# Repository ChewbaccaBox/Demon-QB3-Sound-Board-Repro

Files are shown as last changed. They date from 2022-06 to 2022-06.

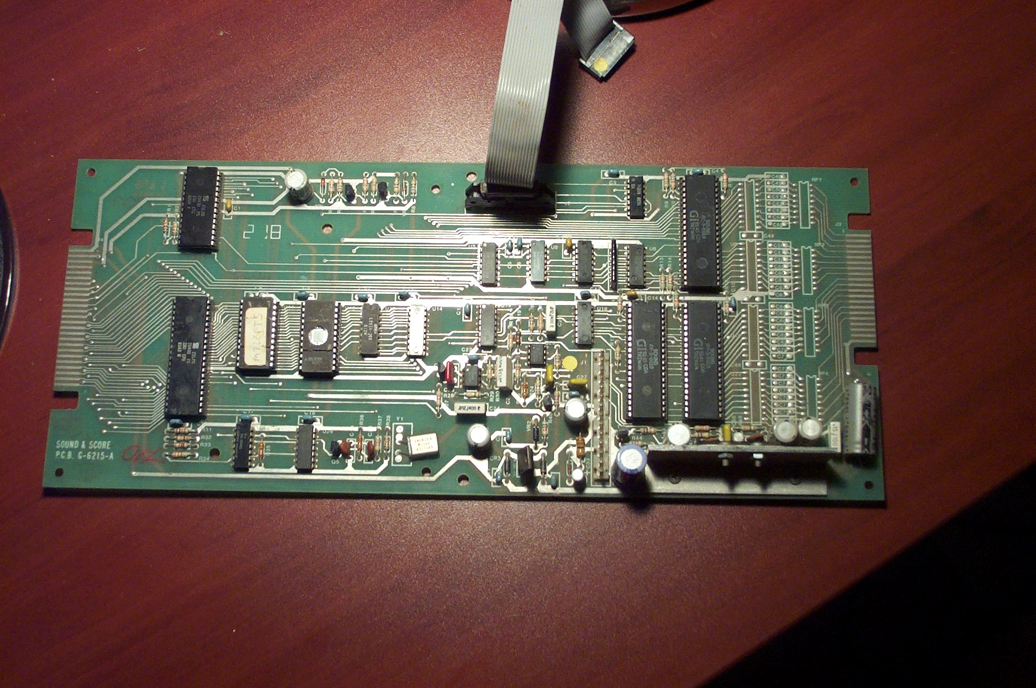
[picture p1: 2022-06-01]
Images/other.png

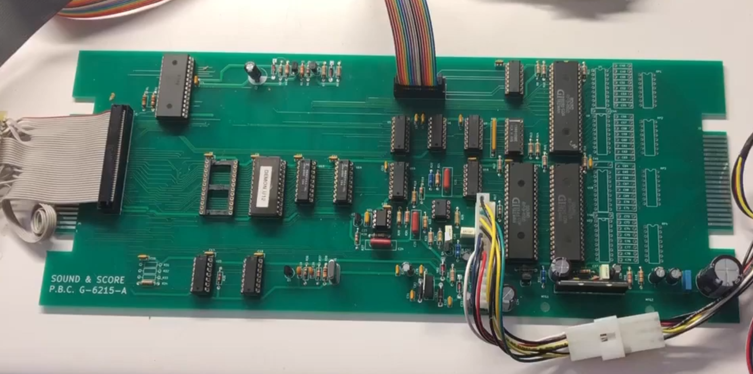
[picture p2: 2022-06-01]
Images/toledoflyerRepro.png

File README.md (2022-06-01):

# Demon-QB3-Sound-Board

***UNTESTED AND POSSIBLY INCOMPLETE***\
Gerbers not included because of this.

Here is my reproduction sound board of those
used in Rockola's Demon and QB3, both based
on Cinematronics hardware. 
So, these games are both impossible to find,
and therefore the sound boards are too.
Demon uses practically a standard Cinematronics
CPU board, and QB3 is a bit more complicated
to make hardware for, but this sound board
should work for the two games.
(QB3 has more ram, a color converter PCB, the sound roms
 dumped are broken. But Demon should work with less trouble!)

**TESTING STATUS:**

no clue! gotta double check the schematic based on the original.
This is being built on solely the two schematics (the QB3 one 
looks more accurate/complete, so leaning towards that one)

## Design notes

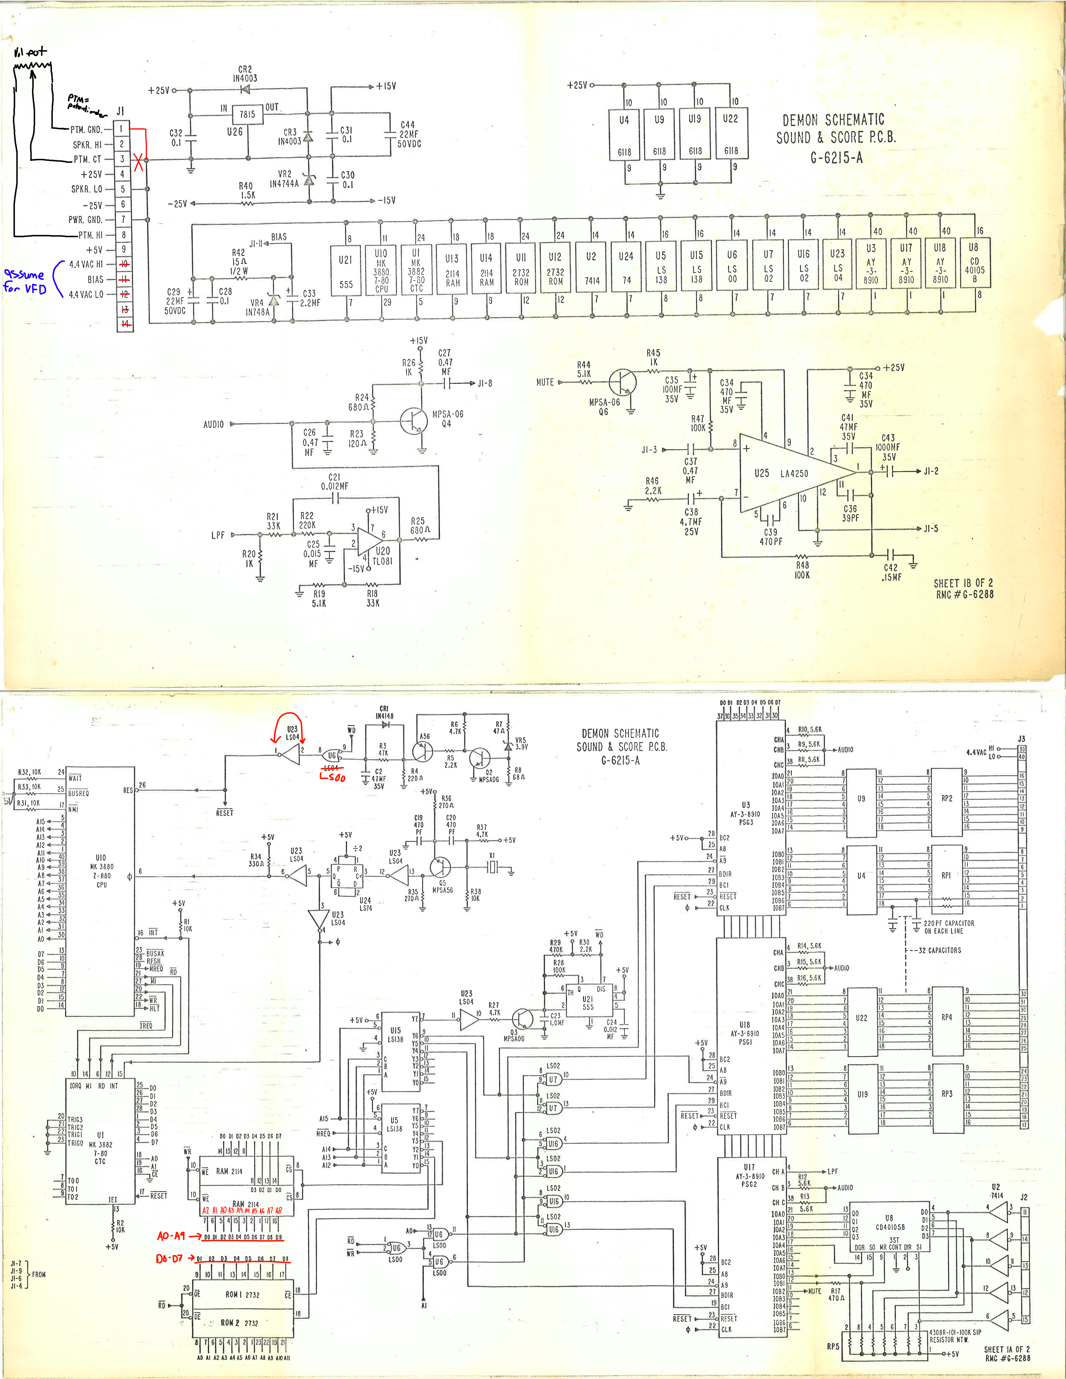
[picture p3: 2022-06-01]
Images/DemonSchematic.png

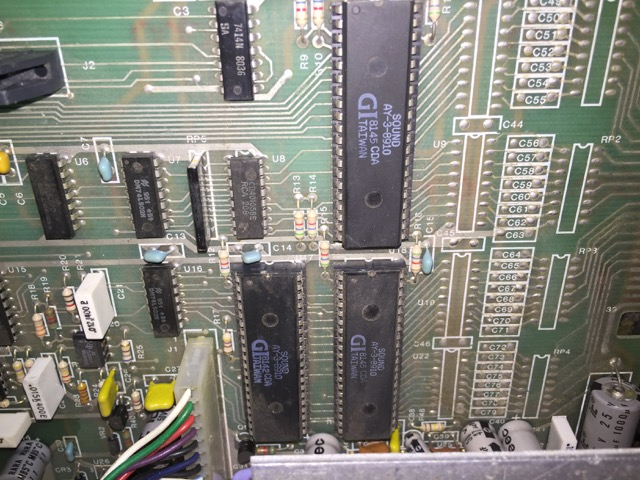
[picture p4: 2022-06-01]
Images/OGpic3.png

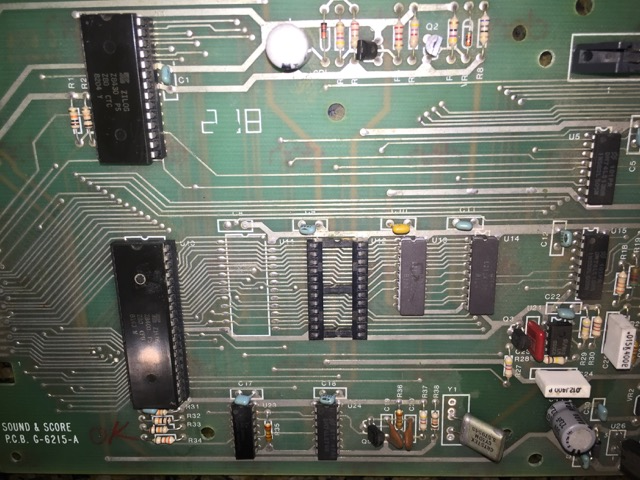
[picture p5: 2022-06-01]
Images/OGpic2.png

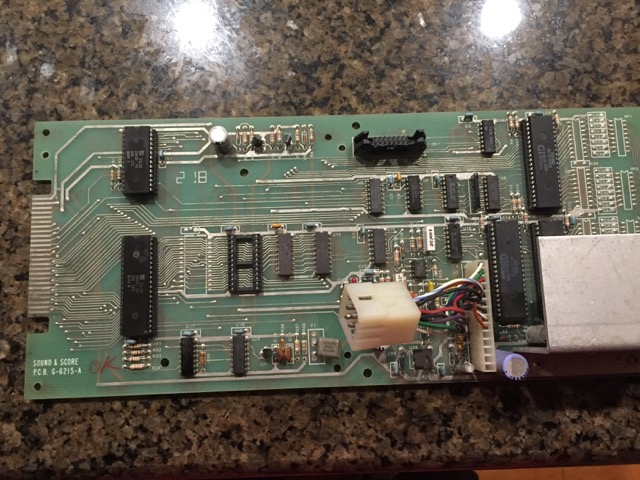
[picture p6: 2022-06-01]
Images/OGpic1.png

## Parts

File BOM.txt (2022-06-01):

    C1 		Right of MK3880			Orange
    C2		47uF				Electrolytic
    C3		Top Left of U2			Blue
    C4		Above U3			
    C5		Left of u6			
    C6		Left of u6			
    C7 		beside u7			
    C8		above u11 (if installed)	
    C9 		above u12			
    C10 	above u13			
    C11 	above u14			
    C12		beside U15			
    C13		above u16			
    C14		above u17			
    C15		Right of R10			
    C16		Below z80			Blue
    C17		above u23			Blue
    C18		above u24			
    C22		above 555

    C19		470pF
    C20		470pF
    C21		0.012uF
    C23		1uF
    C24		0.012uF
    C25		0.015uF
    C26		0.47uF
    C27		0.47uF
    C28		0.1uF
    C29		22uF
    C30		0.1uF
    C31		0.1uF
    C32		0.1uF
    C33		2.2uF
    C34		470uF
    C35		100uF
    C36		39pF
    C37		0.47uF
    C38		4.7uF
    C39		470pF
    C40		470uF
    C41		47uF
    C42		.15uF
    C43		1000uF
    C44		22nF
    C45		above u19
    C46		above u22

    C47		?

    C48 - C79   =   CA1 - CA32

    CA1		220pF
    CA2		220pF
    CA3		220pF
    CA4		220pF
    CA5		220pF
    CA6		220pF
    CA7		220pF
    CA8		220pF
    CA9		220pF
    CA10	220pF
    CA11	220pF
    CA12	220pF
    CA13	220pF
    CA14	220pF
    CA15	220pF
    CA16	220pF
    CA17	220pF
    CA18	220pF
    CA19	220pF
    CA20	220pF
    CA21	220pF
    CA22	220pF
    CA23	220pF
    CA24	220pF
    CA25	220pF
    CA26	220pF
    CA27	220pF
    CA28	220pF
    CA29	220pF
    CA30	220pF
    CA31	220pF
    CA32	220pF

    CR1		1N4148
    CR2		1N4003
    CR3		1N4003

    J1		14 pin .156 header, 1 x 14
    J2		16 pin .1 header, 2 x 8
    J3		(Edge connector, part of PCB already)
    J4		(Edge connector, part of PCB already)

Transistors
	5 * MPSA06, 1 * MPSA92

    Q1		MPSA06
    Q2		MPSA06
    Q3		MPSA06
    Q4		MPSA06
    Q5		MPSA92
    Q6		MPSA06

Resistors

    R1		10K
    R2		10K
    R3		47K
    R4		220
    R5		47K
    R6		4.7K
    R7		47K
    R8		68
    R9		5.6K
    R10		5.6K
    R11		5.6K
    R12		5.6K
    R13		5.6K
    R14		5.6K
    R15		5.6K
    R16		5.6K
    R17		470
    R18		33K
    R19		5.1K
    R20		1K
    R21		33K
    R22		220K
    R23		120
    R24		680
    R25		680
    R26		1K
    R27		4.7K
    R28		100K
    R29		470K
    R30		2.2K
    R31		10K
    R32		10K
    R33		10K
    R34		330
    R35		270
    R36		270
    R37		4.7k
    R38		10K
    R40		1.5K
    R42		15
    R44		5.1K
    R45		1K
    R46		2.2k
    R47		100K
    R48		100K
    RP1		R_Pack08
    RP2		R_Pack08
    RP3		R_Pack08
    RP4		R_Pack08
    RP5		100K

Chips / Packages
	3 * AY-3-8910, 2 * 2114, 2 * 2732, 1 * Z80, 1 * Z

    U1		MK3882
    U2		74LS14
    U3		AY-3-8910
    U4		6118
    U5		74LS138
    U6		74LS00
    U7		74LS02
    U8		CD40105B
    U9		6118
    U10		Z80CPU
    U11		2732
    U12		2732
    U13		2114
    U14		2114
    U15		74LS138
    U16		74LS02
    U17		AY-3-8910
    U18		AY-3-8910
    U19		6118
    U20		TL081
    U21		555
    U22		6118
    U23		74LS04
    U24		74LS74
    U25		LA4250
    U26		7815
    VR2		1N4744A
    VR4		1N748A
    VR5		?

Crystals
	1 * 3.579 MHz

    X1		3.579 MHz

chips

3 x AY-3-8910
1 x LA4250
1 x TL081
2 x 2114
1 x 2732	
1 x CD40105B
1 x Z80
1 x Z80-CTC

1 x 74LS00
2 x 74LS02
1 x 74LS04
1 x 74LS14
1 x 74LS74
2 x 74LS138

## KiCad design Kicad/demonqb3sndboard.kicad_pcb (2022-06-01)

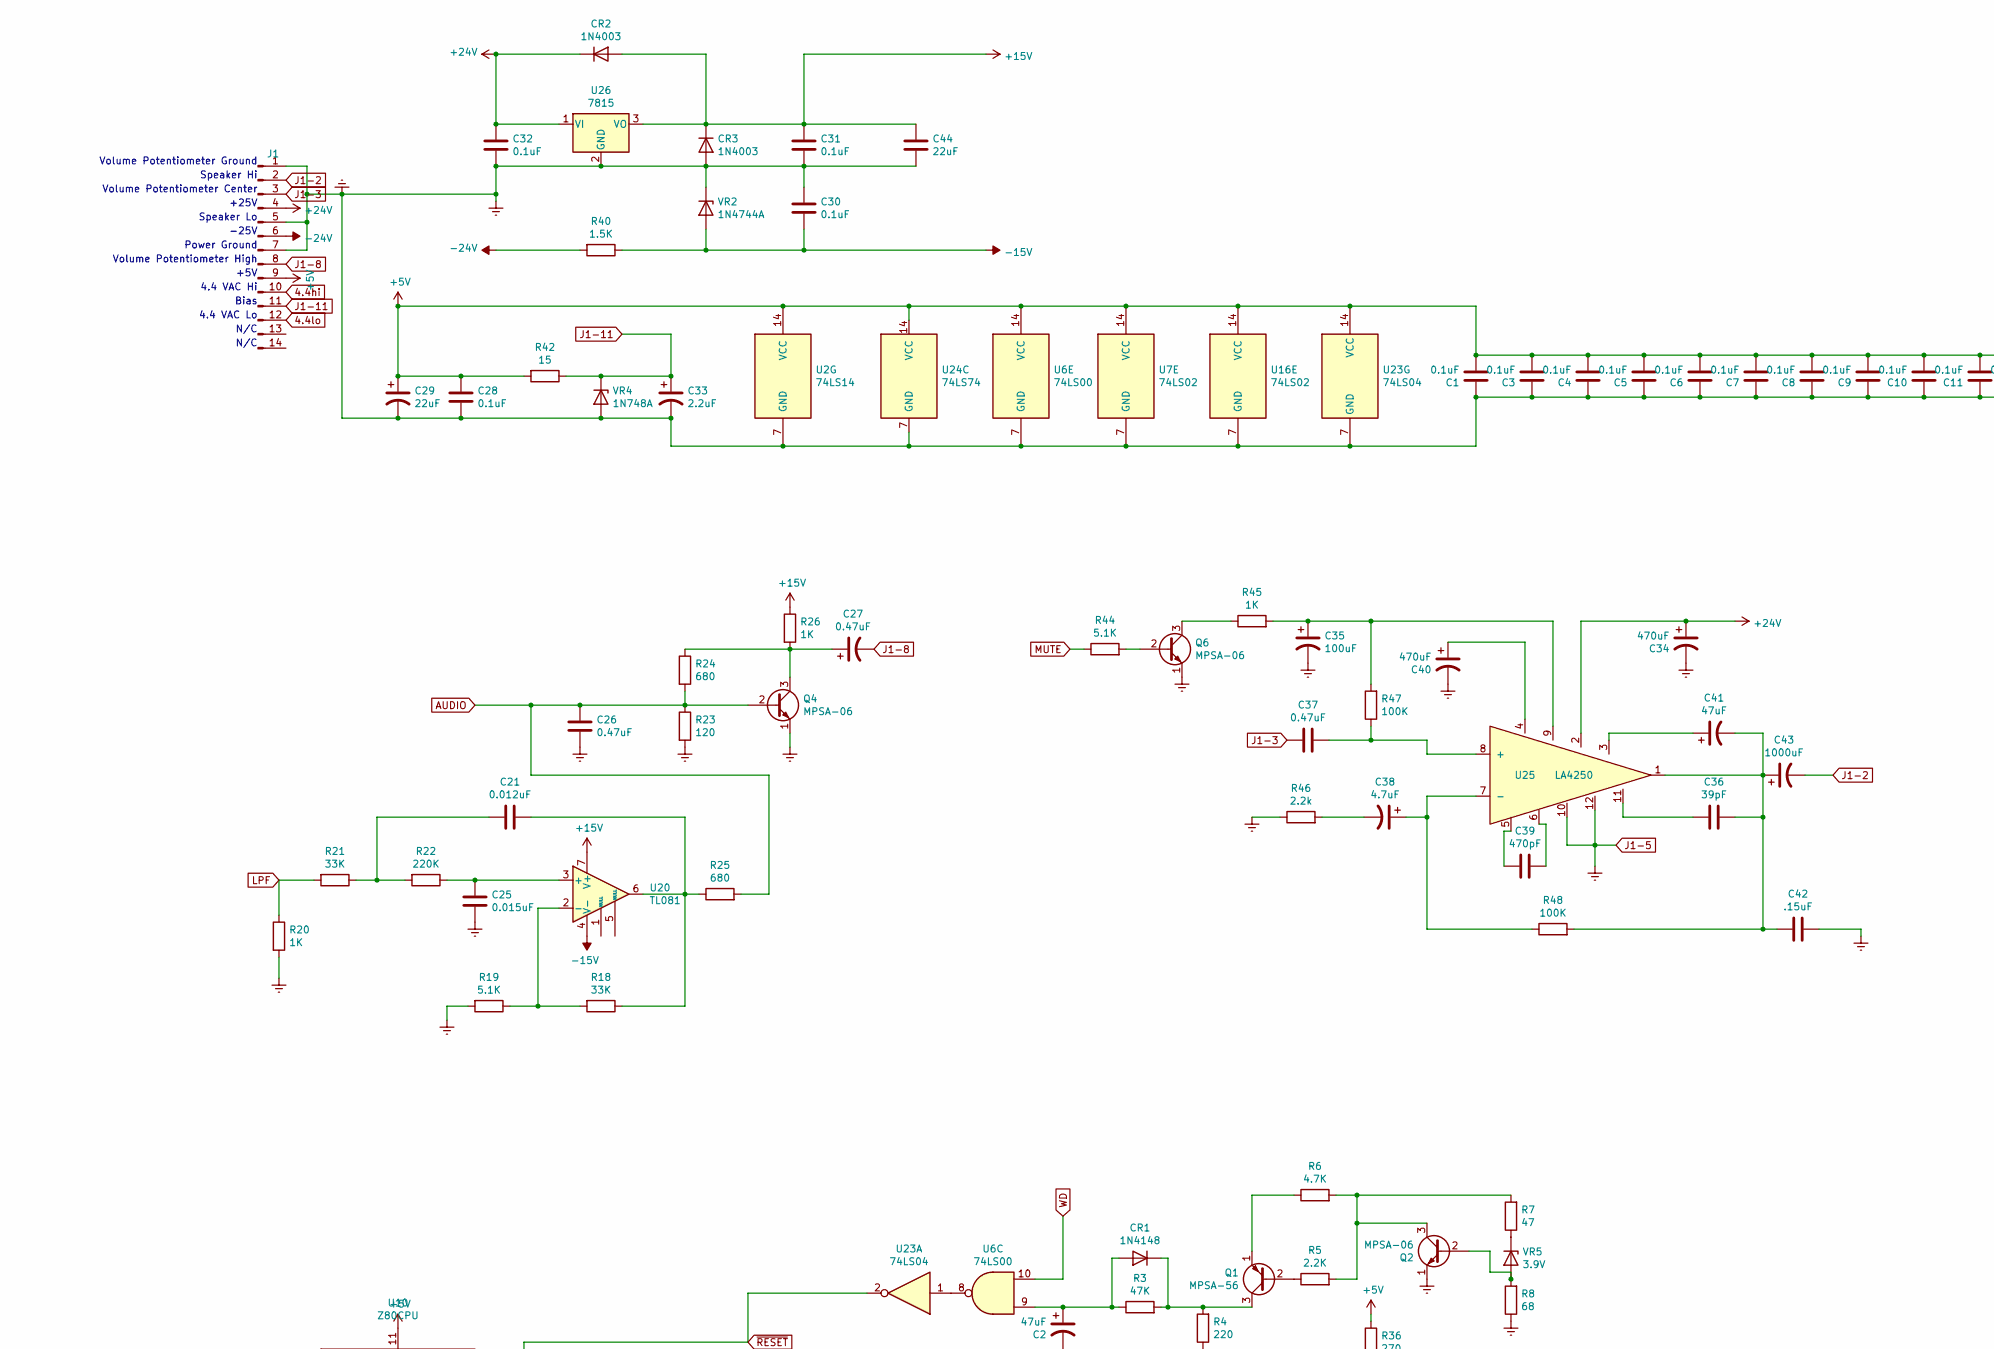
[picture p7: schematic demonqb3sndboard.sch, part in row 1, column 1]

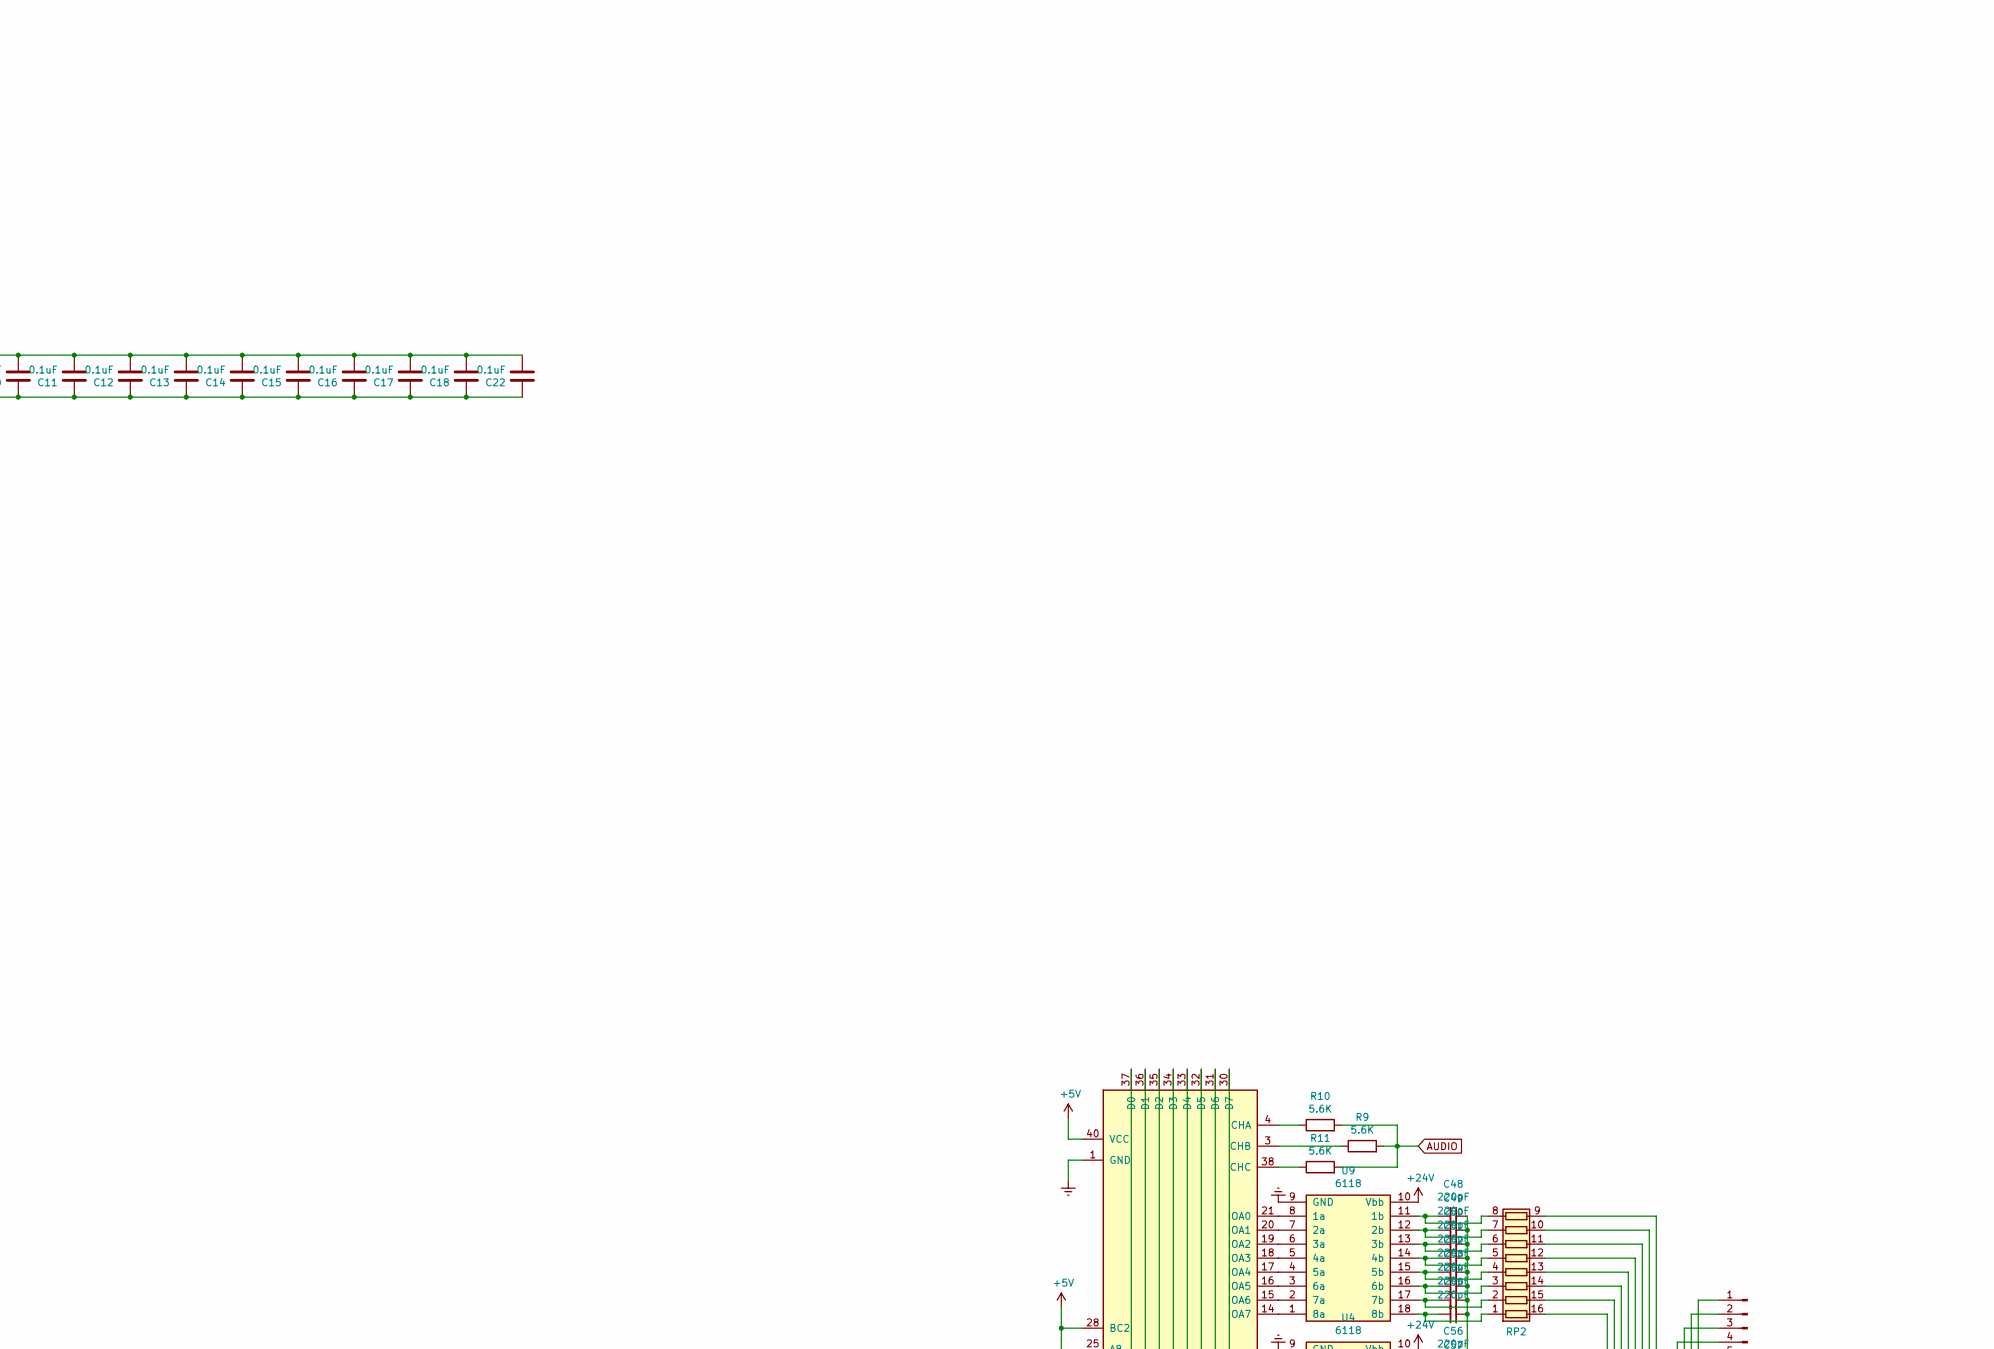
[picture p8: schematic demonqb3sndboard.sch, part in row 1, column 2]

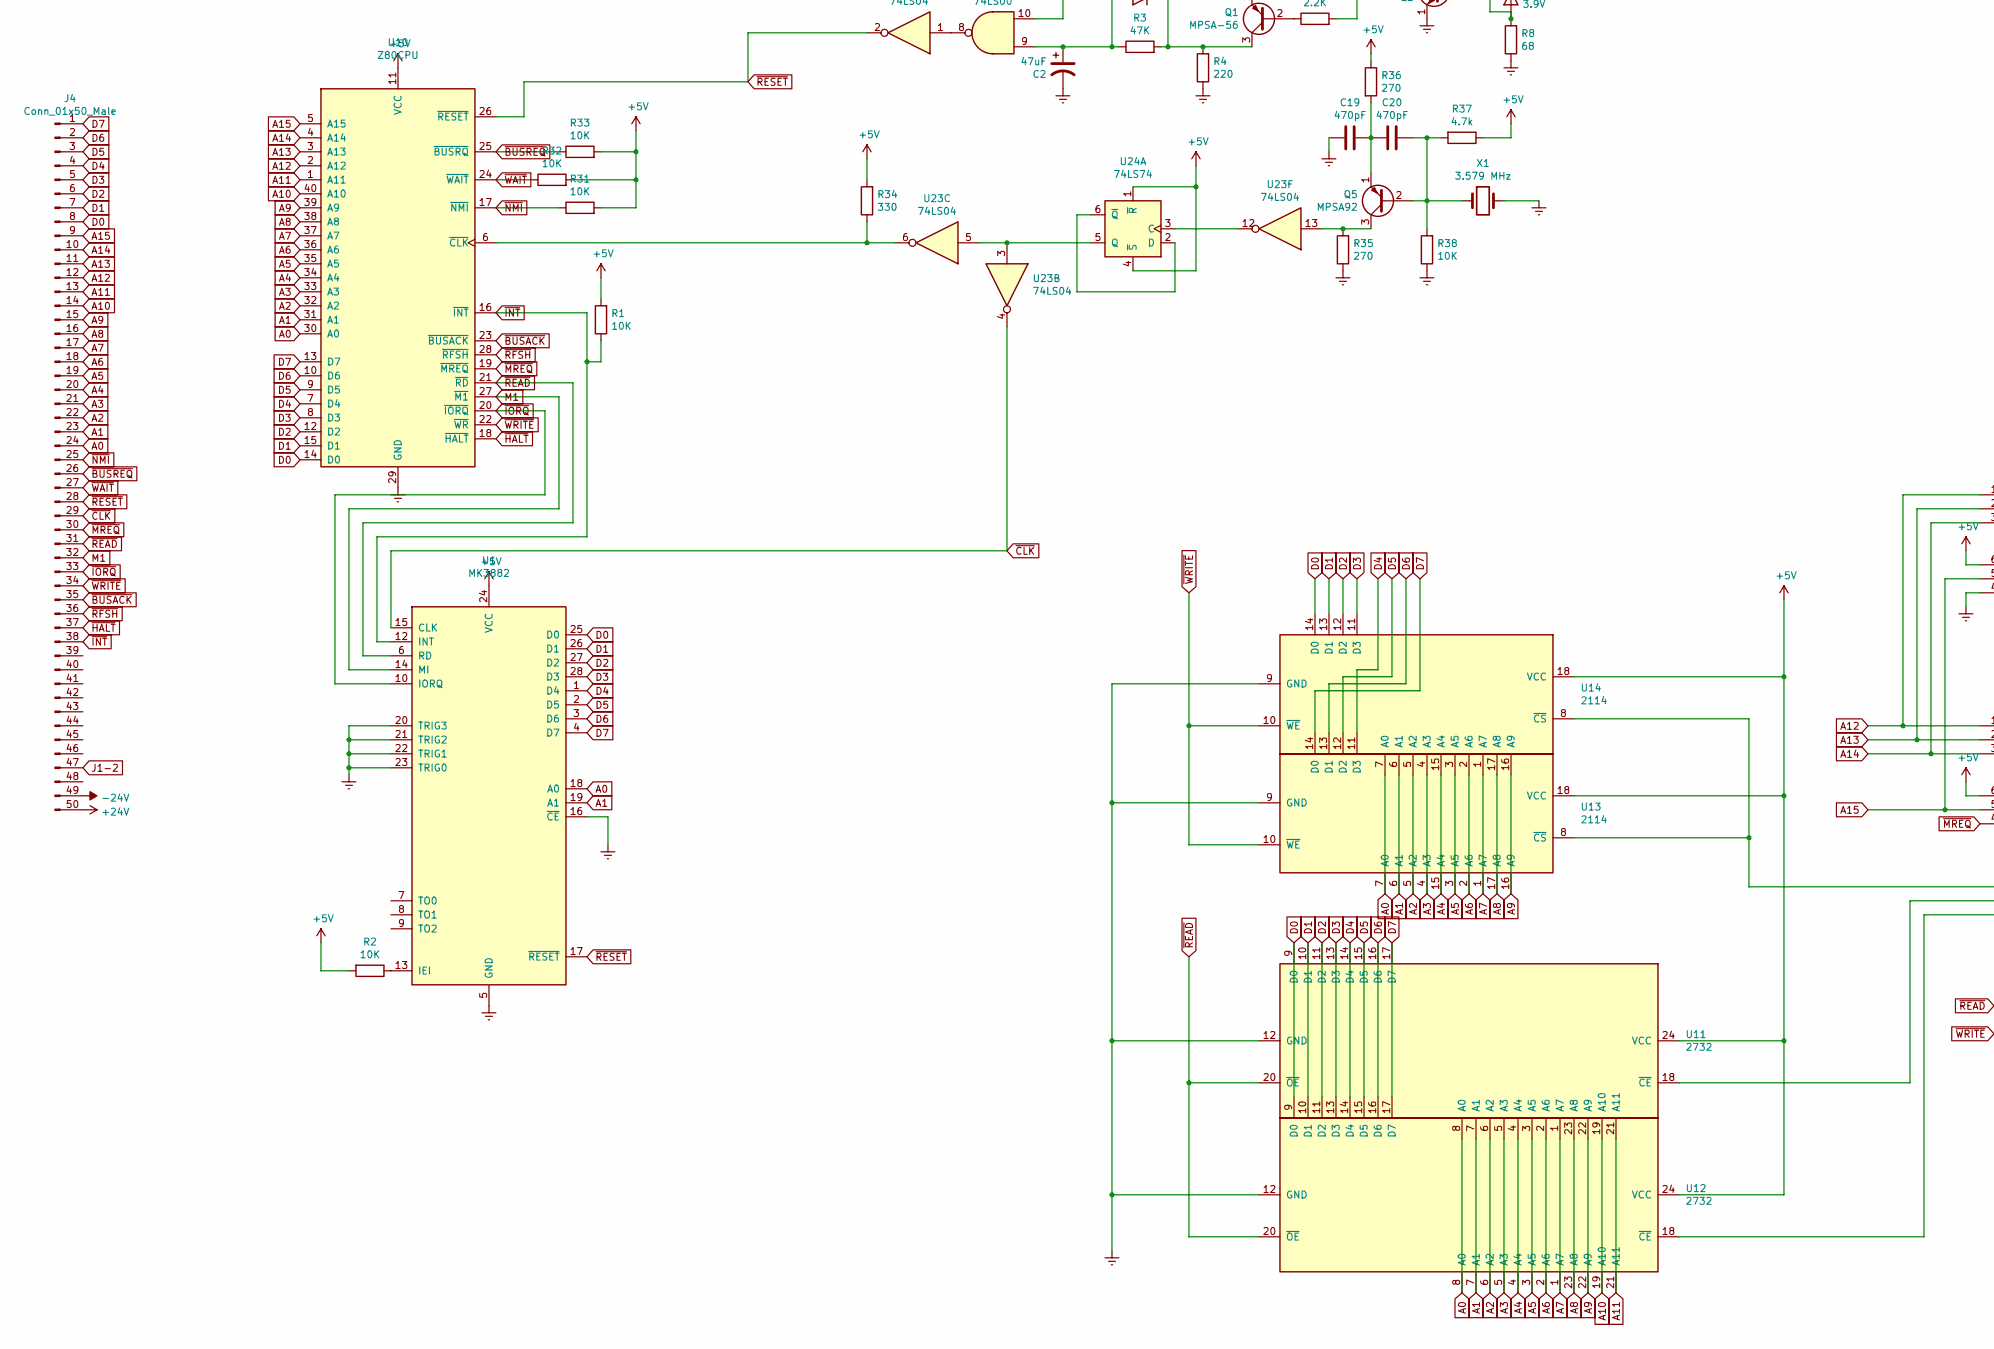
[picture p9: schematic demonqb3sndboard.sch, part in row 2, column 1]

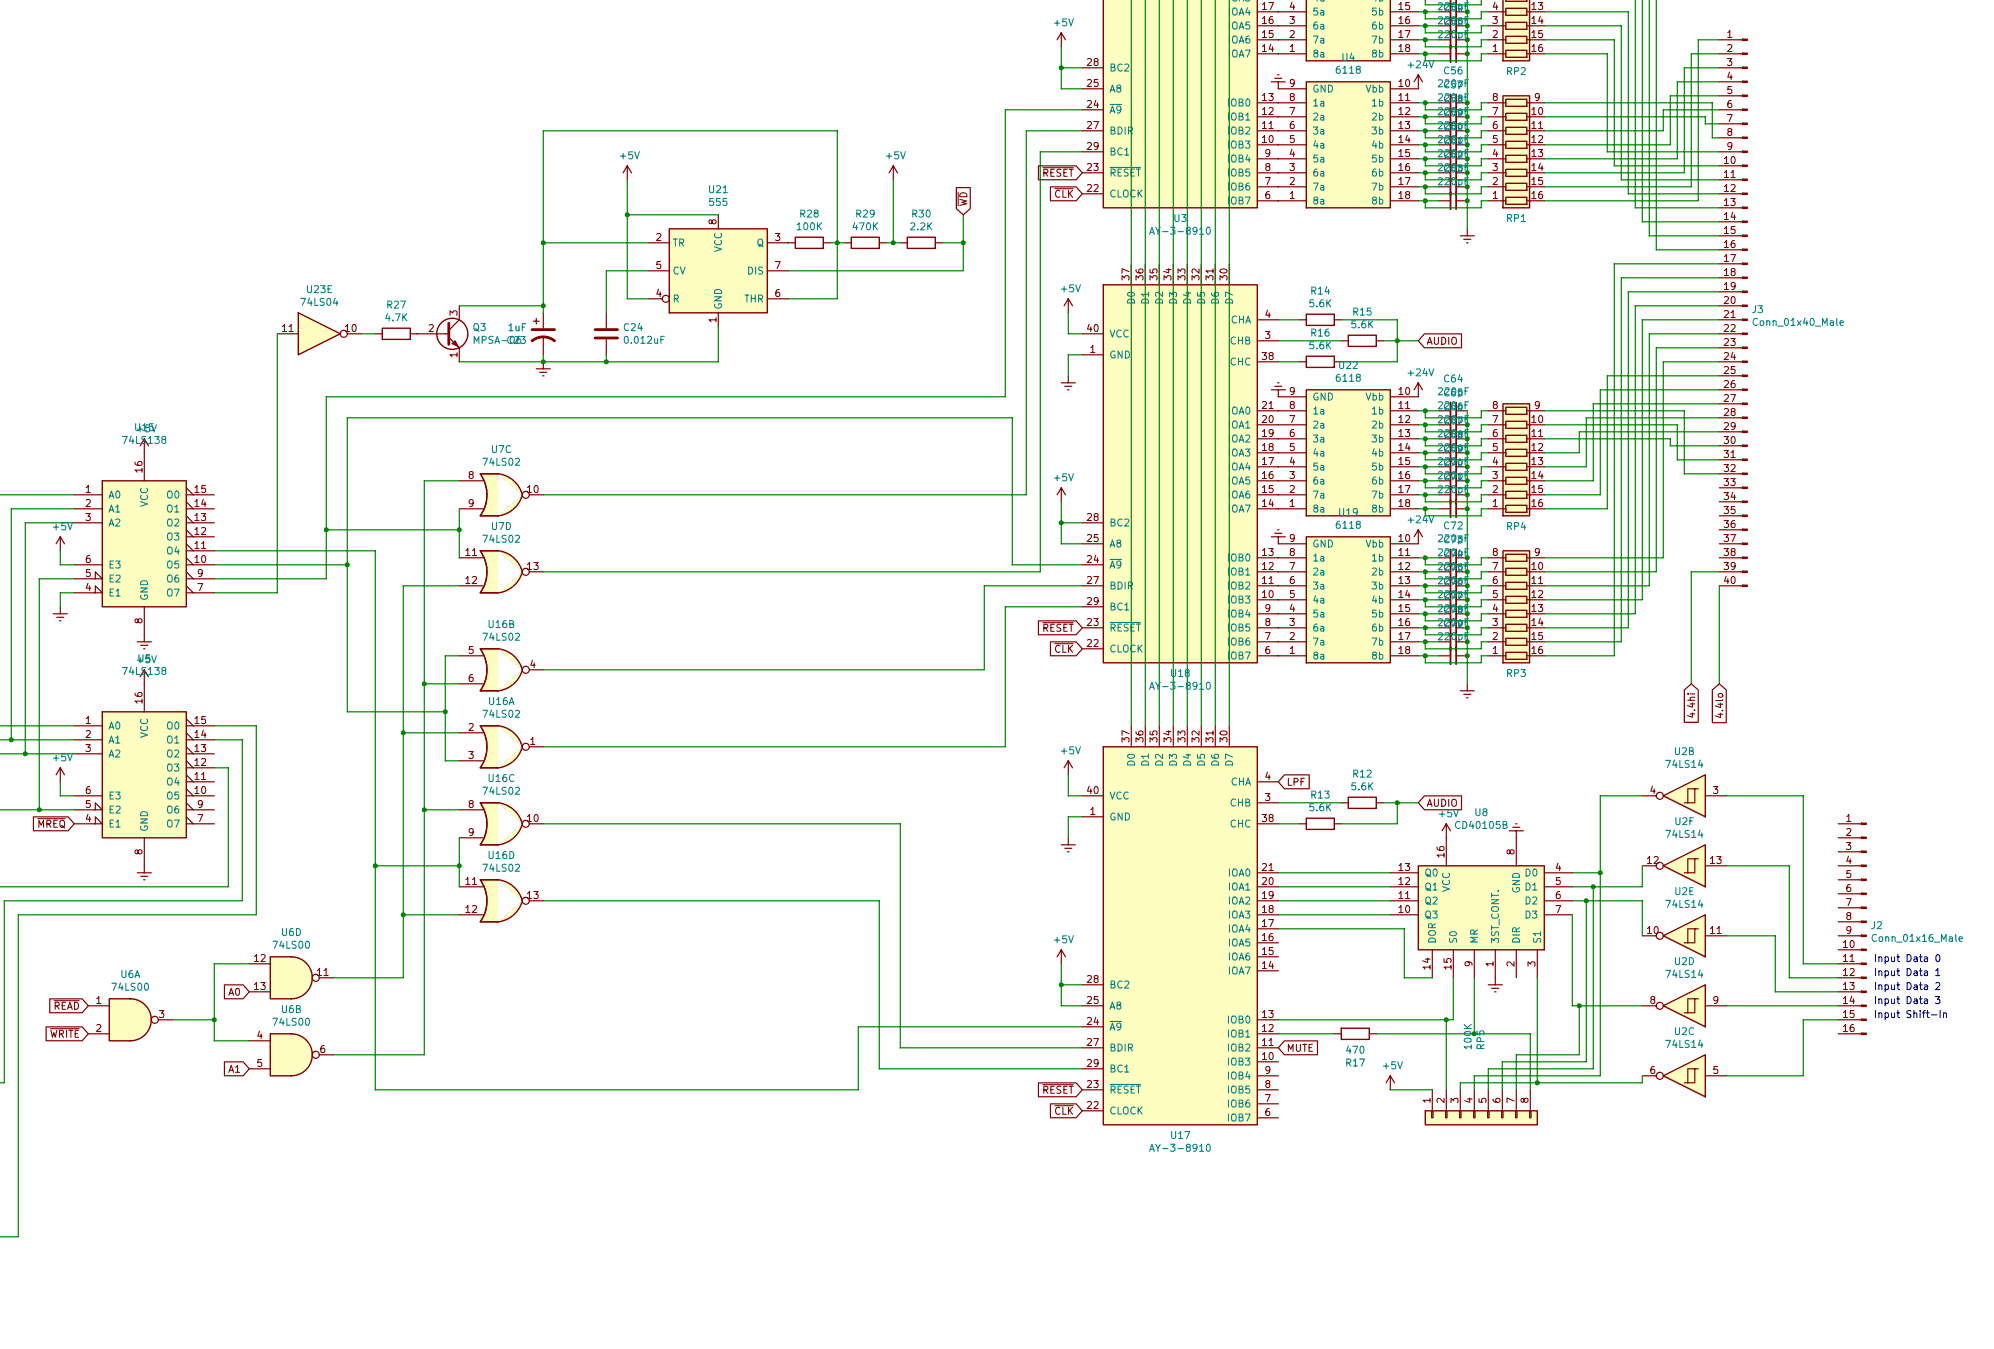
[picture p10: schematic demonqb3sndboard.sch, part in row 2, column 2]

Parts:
C1, C3, C4, C5, C6, C7, C8, C9, C10, C11, C12, C13, C14, C15, C16, C17, C18, C22, C28, C30, C31, C32: 0.1uF; C_Disc_D7.0mm_W2.5mm_P5.00mm
C2: 47uF; CP_Radial_D10.0mm_P5.00mm
C19, C20, C39: 470pF; C_Disc_D7.0mm_W2.5mm_P5.00mm
C21, C24: 0.012uF; C_Disc_D12.5mm_W5.0mm_P10.00mm
C23: 1uF; C_Disc_D10.0mm_W2.5mm_P5.00mm
C25: 0.015uF; C_Disc_D12.5mm_W5.0mm_P10.00mm
C26, C27: 0.47uF; C_Disc_D7.0mm_W2.5mm_P5.00mm
C29, C44: 22uF; C_Disc_D7.0mm_W2.5mm_P5.00mm
C33: 2.2uF; C_Disc_D7.0mm_W2.5mm_P5.00mm
C34, C40: 470uF; CP_Radial_D10.0mm_P5.00mm
C35: 100uF; CP_Radial_D5.0mm_P2.50mm
C36: 39pF; C_Disc_D7.0mm_W2.5mm_P5.00mm
C37: 0.47uF; CP_Radial_D5.0mm_P2.50mm
C38: 4.7uF; C_Disc_D7.0mm_W2.5mm_P5.00mm
C41: 47uF; CP_Radial_D5.0mm_P2.50mm
C42: .15uF; C_Disc_D7.0mm_W2.5mm_P5.00mm
C43: 1000uF; CP_Axial_L30.0mm_D10.0mm_P35.00mm_Horizontal
C48, C49, C50, C51, C52, C53, C54, C55, C56, C57, C58, C59, C60, C61, C62, C63, C64, C65, C66, C67, C68, C69, C70, C71, C72, C73, C74, C75, C76, C77, C78, C79: 220pF; C_Disc_D7.0mm_W2.5mm_P5.00mm
CR1: 1N4148; D_DO-41_SOD81_P10.16mm_Horizontal
CR2, CR3: 1N4003; D_DO-41_SOD81_P10.16mm_Horizontal
J1: Conn_01x14_Male; PinHeader_01x14_0.156
J2: Conn_01x16_Male; PinHeader_2x08_P2.54mm_Vertical
J3: Conn_01x40_Male; 40pinEdgeConnector2.54mm
J4: Conn_01x50_Male; 50pinEdgeConnector2.54mm
Q1: MPSA-56; TO-92_Inline
Q2, Q3, Q4, Q6: MPSA-06; TO-92_Inline
Q5: MPSA92; TO-92_Inline
R1, R2, R31, R32, R33, R38: 10K; R_Axial_DIN0309_L9.0mm_D3.2mm_P12.70mm_Horizontal
R3: 47K; R_Axial_DIN0309_L9.0mm_D3.2mm_P12.70mm_Horizontal
R4: 220; R_Axial_DIN0309_L9.0mm_D3.2mm_P12.70mm_Horizontal
R5, R30: 2.2K; R_Axial_DIN0309_L9.0mm_D3.2mm_P12.70mm_Horizontal
R6, R27: 4.7K; R_Axial_DIN0309_L9.0mm_D3.2mm_P12.70mm_Horizontal
R7: 47; R_Axial_DIN0309_L9.0mm_D3.2mm_P12.70mm_Horizontal
R8: 68; R_Axial_DIN0309_L9.0mm_D3.2mm_P12.70mm_Horizontal
R9, R10, R11, R12, R13, R14, R15, R16: 5.6K; R_Axial_DIN0309_L9.0mm_D3.2mm_P12.70mm_Horizontal
R17: 470; R_Axial_DIN0309_L9.0mm_D3.2mm_P12.70mm_Horizontal
R18, R21: 33K; R_Axial_DIN0309_L9.0mm_D3.2mm_P12.70mm_Horizontal
R19, R44: 5.1K; R_Axial_DIN0309_L9.0mm_D3.2mm_P12.70mm_Horizontal
R20, R26, R45: 1K; R_Axial_DIN0309_L9.0mm_D3.2mm_P12.70mm_Horizontal
R22: 220K; R_Axial_DIN0309_L9.0mm_D3.2mm_P12.70mm_Horizontal
R23: 120; R_Axial_DIN0309_L9.0mm_D3.2mm_P12.70mm_Horizontal
R24, R25: 680; R_Axial_DIN0309_L9.0mm_D3.2mm_P12.70mm_Horizontal
R28, R47, R48: 100K; R_Axial_DIN0309_L9.0mm_D3.2mm_P12.70mm_Horizontal
R29: 470K; R_Axial_DIN0309_L9.0mm_D3.2mm_P12.70mm_Horizontal
R34: 330; R_Axial_DIN0309_L9.0mm_D3.2mm_P12.70mm_Horizontal
R35, R36: 270; R_Axial_DIN0309_L9.0mm_D3.2mm_P12.70mm_Horizontal
R37: 4.7k; R_Axial_DIN0309_L9.0mm_D3.2mm_P12.70mm_Horizontal
R40: 1.5K; R_Axial_DIN0309_L9.0mm_D3.2mm_P12.70mm_Horizontal
R42: 15; R_Axial_DIN0309_L9.0mm_D3.2mm_P12.70mm_Horizontal
R46: 2.2k; R_Axial_DIN0309_L9.0mm_D3.2mm_P12.70mm_Horizontal
RP1, RP2, RP3, RP4: R_Pack08; DIP-16_W7.62mm_LongPads
RP5: 100K; PinHeader_1x08_P2.54mm_Vertical
U1: MK3882; DIP-28_W15.24mm_LongPads
U2: 74LS14; DIP-14_W7.62mm_LongPads
U3, U17, U18: AY-3-8910; DIP-40_W15.24mm_LongPads
U4, U9, U19, U22: 6118; DIP-18_W7.62mm_LongPads
U5, U15: 74LS138; DIP-16_W7.62mm_LongPads
U6: 74LS00; DIP-14_W7.62mm_LongPads
U7, U16: 74LS02; DIP-14_W7.62mm_LongPads
U8: CD40105B; DIP-16_W7.62mm_LongPads
U10: Z80CPU; DIP-40_W15.24mm_LongPads
U11, U12: 2732; DIP-24_W15.24mm_LongPads
U13, U14: 2114; DIP-18_W7.62mm_LongPads
U20: TL081; DIP-8_W7.62mm_LongPads
U21: 555; DIP-8_W7.62mm_LongPads
U23: 74LS04; DIP-14_W7.62mm_LongPads
U24: 74LS74; DIP-14_W7.62mm_LongPads
U25: LA4250; PinSocket_1x12_P2.54mm_Vertical
U26: 7815; TO-220-3_Vertical
VR2: 1N4744A; D_DO-41_SOD81_P10.16mm_Horizontal
VR4: 1N748A; D_DO-41_SOD81_P10.16mm_Horizontal
VR5: 3.9V; D_DO-41_SOD81_P10.16mm_Horizontal
X1: 3.579 MHz; Crystal_HC18-U_Vertical

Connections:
4.4hi: J1.10, J3.39
4.4lo: J1.12, J3.40
+5V: C1.2, C3.2, C4.2, C5.2, C6.2, C7.2, C8.2, C9.2, C10.2, C11.2, C12.2, C13.2, C14.2, C15.2, C16.2, C17.2, C18.2, C22.2, C28.1, C29.1, J1.9, R1.2, R2.2, R29.2, R30.1, R31.2, R32.2, R33.2, R34.2, R36.1, R37.1, R42.2, RP5.1, U1.24 (VCC), U2.14 (VCC), U3.25 (A8), U3.28 (BC2), U3.40 (VCC), U5.6 (E3), U5.16 (VCC), U6.14 (VCC), U7.14 (VCC), U8.16 (VCC), U10.11 (VCC), U11.24 (VCC), U12.24 (VCC), U13.18 (VCC), U14.18 (VCC), U15.6 (E3), U15.16 (VCC), U16.14 (VCC), U17.25 (A8), U17.28 (BC2), U17.40 (VCC), U18.25 (A8), U18.28 (BC2), U18.40 (VCC), U21.4 (R), U21.8 (VCC), U23.14 (VCC), U24.1 (~R), U24.4 (~S), U24.14 (VCC)
+15V: C31.1, C44.1, CR2.2 (A), CR3.1 (K), R26.1, U20.7 (V+), U26.3 (VO)
+24V: C32.1, C34.1, CR2.1 (K), J1.4, J4.50, U4.10 (Vbb), U9.10 (Vbb), U19.10 (Vbb), U22.10 (Vbb), U25.2, U26.1 (VI)
-15V: C30.2, R40.1, U20.4 (V-), VR2.2 (A)
-24V: J1.6, J4.49, R40.2
A0: J4.24, U1.18 (A0), U6.13, U10.30 (A0), U11.8 (A0), U12.8 (A0), U13.7 (A0), U14.7 (A0)
A1: J4.23, U1.19 (A1), U6.5, U10.31 (A1), U11.7 (A1), U12.7 (A1), U13.6 (A1), U14.6 (A1)
A2: J4.22, U10.32 (A2), U11.6 (A2), U12.6 (A2), U13.5 (A2), U14.5 (A2)
A3: J4.21, U10.33 (A3), U11.5 (A3), U12.5 (A3), U13.4 (A3), U14.4 (A3)
A4: J4.20, U10.34 (A4), U11.4 (A4), U12.4 (A4), U13.15 (A4), U14.15 (A4)
A5: J4.19, U10.35 (A5), U11.3 (A5), U12.3 (A5), U13.3 (A5), U14.3 (A5)
A6: J4.18, U10.36 (A6), U11.2 (A6), U12.2 (A6), U13.2 (A6), U14.2 (A6)
A7: J4.17, U10.37 (A7), U11.1 (A7), U12.1 (A7), U13.1 (A7), U14.1 (A7)
A8: J4.16, U10.38 (A8), U11.23 (A8), U12.23 (A8), U13.17 (A8), U14.17 (A8)
A9: J4.15, U10.39 (A9), U11.22 (A9), U12.22 (A9), U13.16 (A9), U14.16 (A9)
A10: J4.14, U10.40 (A10), U11.19 (A10), U12.19 (A10)
A11: J4.13, U10.1 (A11), U11.21 (A11), U12.21 (A11)
A12: J4.12, U5.1 (A0), U10.2 (A12), U15.1 (A0)
A13: J4.11, U5.2 (A1), U10.3 (A13), U15.2 (A1)
A14: J4.10, U5.3 (A2), U10.4 (A14), U15.3 (A2)
A15: J4.9, U5.5 (E2), U10.5 (A15), U15.5 (E2)
AUDIO: C26.2, Q4.2 (B), R9.2, R10.2, R11.2, R12.2, R13.2, R14.2, R15.2, R16.2, R23.1, R24.2, R25.2
D0: J4.8, U1.25 (D0), U10.14 (D0), U11.9 (D0), U12.9 (D0), U14.14 (D0)
D1: J4.7, U1.26 (D1), U10.15 (D1), U11.10 (D1), U12.10 (D1), U14.13 (D1)
D2: J4.6, U1.27 (D2), U10.12 (D2), U11.11 (D2), U12.11 (D2), U14.12 (D2)
D3: J4.5, U1.28 (D3), U10.8 (D3), U11.13 (D3), U12.13 (D3), U14.11 (D3)
D4: J4.4, U1.1 (D4), U10.7 (D4), U11.14 (D4), U12.14 (D4), U13.11 (D3)
D5: J4.3, U1.2 (D5), U10.9 (D5), U11.15 (D5), U12.15 (D5), U13.12 (D2)
D6: J4.2, U1.3 (D6), U10.10 (D6), U11.16 (D6), U12.16 (D6), U13.13 (D1)
D7: J4.1, U1.4 (D7), U10.13 (D7), U11.17 (D7), U12.17 (D7), U13.14 (D0)
J1-2: C43.2, J1.2, J4.47
J1-3: C37.1, J1.3
J1-5: C1.1, C2.2, C3.1, C4.1, C5.1, C6.1, C7.1, C8.1, C9.1, C10.1, C11.1, C12.1, C13.1, C14.1, C15.1, C16.1, C17.1, C18.1, C19.2, C22.1, C23.2, C24.1, C25.2, C26.1, C28.2, C29.2, C30.1, C31.2, C32.2, C33.2, C34.2, C35.2, C40.2, C42.2, C44.2, C48.1, C49.1, C50.1, C51.1, C52.1, C53.1, C54.1, C55.1, C56.1, C57.1, C58.1, C59.1, C60.1, C61.1, C62.1, C63.1, C64.1, C65.1, C66.1, C67.1, C68.1, C69.1, C70.1, C71.1, C72.1, C73.1, C74.1, C75.1, C76.1, C77.1, C78.1, C79.1, CR3.2 (A), J1.1, J1.5, J1.7, Q2.1 (E), Q3.1 (E), Q4.1 (E), Q6.1 (E), R4.1, R8.1, R19.2, R20.2, R23.2, R35.1, R38.1, R46.1, U1.5 (GND), U1.16 (~CE~), U1.20 (TRIG3), U1.21 (TRIG2), U1.22 (TRIG1), U1.23 (TRIG0), U2.7 (GND), U3.1 (GND), U4.9 (GND), U5.8 (GND), U6.7 (GND), U7.7 (GND), U8.1 (3ST_CONT.), U8.8 (GND), U9.9 (GND), U10.29 (GND), U11.12 (GND), U12.12 (GND), U13.9 (GND), U14.9 (GND), U15.4 (E1), U15.8 (GND), U16.7 (GND), U17.1 (GND), U18.1 (GND), U19.9 (GND), U21.1 (GND), U22.9 (GND), U23.7 (GND), U24.7 (GND), U25.10, U25.12, U26.2 (GND), VR2.1 (K), VR4.2 (A), X1.2
J1-8: C27.2, J1.8
J1-11: C33.1, J1.11, R42.1, VR4.1 (K)
LPF: R20.1, R21.2, U17.4 (CHA)
M1: J4.32, U1.14 (MI), U10.27 (~M1~)
MUTE: R44.1, U17.11 (IOB2)
unnamed: C2.1, CR1.2 (A), R3.1, U6.9
unnamed: C19.1, C20.2, Q5.1 (E), R36.2
unnamed: C20.1, Q5.2 (B), R37.2, R38.2, X1.1
unnamed: C21.1, R21.1, R22.2
unnamed: C21.2, R18.1, R25.1, U20.6
unnamed: C23.1, Q3.3 (C), R28.2, R29.1, U21.2 (TR), U21.6 (THR)
unnamed: C24.2, U21.5 (CV)
unnamed: C25.1, R22.1, U20.3 (+)
unnamed: C27.1, Q4.3 (C), R24.1, R26.2
unnamed: C35.1, R45.2, R47.2, U25.9
unnamed: C36.1, U25.11
unnamed: C36.2, C41.2, C42.1, C43.1, R48.2, U25.1
unnamed: C37.2, R47.1, U25.8 (+)
unnamed: C38.1, R48.1, U25.7 (-)
unnamed: C38.2, R46.2
unnamed: C39.1, U25.5
unnamed: C39.2, U25.6
unnamed: C40.1, U25.4
unnamed: C41.1, U25.3
unnamed: C48.2, RP2.8 (R8.1), U9.11 (1b)
unnamed: C49.2, RP2.7 (R7.1), U9.12 (2b)
unnamed: C50.2, RP2.6 (R6.1), U9.13 (3b)
unnamed: C51.2, RP2.5 (R5.1), U9.14 (4b)
unnamed: C52.2, RP2.4 (R4.1), U9.15 (5b)
unnamed: C53.2, RP2.3 (R3.1), U9.16 (6b)
unnamed: C54.2, RP2.2 (R2.1), U9.17 (7b)
unnamed: C55.2, RP2.1 (R1.1), U9.18 (8b)
unnamed: C56.2, RP1.8 (R8.1), U4.11 (1b)
unnamed: C57.2, RP1.7 (R7.1), U4.12 (2b)
unnamed: C58.2, RP1.6 (R6.1), U4.13 (3b)
unnamed: C59.2, RP1.5 (R5.1), U4.14 (4b)
unnamed: C60.2, RP1.4 (R4.1), U4.15 (5b)
unnamed: C61.2, RP1.3 (R3.1), U4.16 (6b)
unnamed: C62.2, RP1.2 (R2.1), U4.17 (7b)
unnamed: C63.2, RP1.1 (R1.1), U4.18 (8b)
unnamed: C64.2, RP4.8 (R8.1), U22.11 (1b)
unnamed: C65.2, RP4.7 (R7.1), U22.12 (2b)
unnamed: C66.2, RP4.6 (R6.1), U22.13 (3b)
unnamed: C67.2, RP4.5 (R5.1), U22.14 (4b)
unnamed: C68.2, RP4.4 (R4.1), U22.15 (5b)
unnamed: C69.2, RP4.3 (R3.1), U22.16 (6b)
unnamed: C70.2, RP4.2 (R2.1), U22.17 (7b)
unnamed: C71.2, RP4.1 (R1.1), U22.18 (8b)
unnamed: C72.2, RP3.8 (R8.1), U19.11 (1b)
unnamed: C73.2, RP3.7 (R7.1), U19.12 (2b)
unnamed: C74.2, RP3.6 (R6.1), U19.13 (3b)
unnamed: C75.2, RP3.5 (R5.1), U19.14 (4b)
unnamed: C76.2, RP3.4 (R4.1), U19.15 (5b)
unnamed: C77.2, RP3.3 (R3.1), U19.16 (6b)
unnamed: C78.2, RP3.2 (R2.1), U19.17 (7b)
unnamed: C79.2, RP3.1 (R1.1), U19.18 (8b)
unnamed: CR1.1 (K), Q1.3 (C), R3.2, R4.2
unnamed: J2.11, U2.3
unnamed: J2.12, U2.13
unnamed: J2.13, U2.11
unnamed: J2.14, U2.9
unnamed: J2.15, U2.5
unnamed: J3.1, RP1.16 (R1.2)
unnamed: J3.2, RP1.15 (R2.2)
unnamed: J3.3, RP1.14 (R3.2)
unnamed: J3.4, RP1.13 (R4.2)
unnamed: J3.5, RP1.12 (R5.2)
unnamed: J3.6, RP1.11 (R6.2)
unnamed: J3.7, RP1.10 (R7.2)
unnamed: J3.8, RP1.9 (R8.2)
unnamed: J3.9, RP2.16 (R1.2)
unnamed: J3.10, RP2.15 (R2.2)
unnamed: J3.11, RP2.14 (R3.2)
unnamed: J3.12, RP2.13 (R4.2)
unnamed: J3.13, RP2.12 (R5.2)
unnamed: J3.14, RP2.11 (R6.2)
unnamed: J3.15, RP2.10 (R7.2)
unnamed: J3.16, RP2.9 (R8.2)
unnamed: J3.17, RP3.16 (R1.2)
unnamed: J3.18, RP3.15 (R2.2)
unnamed: J3.19, RP3.14 (R3.2)
unnamed: J3.20, RP3.13 (R4.2)
unnamed: J3.21, RP3.12 (R5.2)
unnamed: J3.22, RP3.11 (R6.2)
unnamed: J3.23, RP3.10 (R7.2)
unnamed: J3.24, RP3.9 (R8.2)
unnamed: J3.25, RP4.16 (R1.2)
unnamed: J3.26, RP4.15 (R2.2)
unnamed: J3.27, RP4.14 (R3.2)
unnamed: J3.28, RP4.13 (R4.2)
unnamed: J3.29, RP4.12 (R5.2)
unnamed: J3.30, RP4.11 (R6.2)
unnamed: J3.31, RP4.10 (R7.2)
unnamed: J3.32, RP4.9 (R8.2)
unnamed: Q1.1 (E), R6.1
unnamed: Q1.2 (B), R5.1
unnamed: Q2.2 (B), R8.2, VR5.2 (A)
unnamed: Q2.3 (C), R5.2, R6.2, R7.2
unnamed: Q3.2 (B), R27.2
unnamed: Q5.3 (C), R35.2, U23.13
unnamed: Q6.2 (B), R44.2
unnamed: Q6.3 (C), R45.1
unnamed: R2.1, U1.13 (IEI)
unnamed: R7.1, VR5.1 (K)
unnamed: R9.1, U3.3 (CHB)
unnamed: R10.1, U3.4 (CHA)
unnamed: R11.1, U3.38 (CHC)
unnamed: R12.1, U17.3 (CHB)
unnamed: R13.1, U17.38 (CHC)
unnamed: R14.1, U18.4 (CHA)
unnamed: R15.1, U18.3 (CHB)
unnamed: R16.1, U18.38 (CHC)
unnamed: R17.1, RP5.8, U8.9 (MR)
unnamed: R17.2, U17.12 (IOB1)
unnamed: R18.2, R19.1, U20.2 (-)
unnamed: R27.1, U23.10
unnamed: R28.1, U21.3 (Q)
unnamed: R34.1, U10.6 (~CLK~), U23.6
unnamed: RP5.2, U8.15 (S0), U17.13 (IOB0)
unnamed: RP5.3, U2.6, U8.3 (S1)
unnamed: RP5.4, U2.4, U8.4 (D0)
unnamed: RP5.5, U2.12, U8.5 (D1)
unnamed: RP5.6, U2.10, U8.6 (D2)
unnamed: RP5.7, U2.8, U8.7 (D3)
unnamed: U3.6 (IOB7), U4.1 (8a)
unnamed: U3.7 (IOB6), U4.2 (7a)
unnamed: U3.8 (IOB5), U4.3 (6a)
unnamed: U3.9 (IOB4), U4.4 (5a)
unnamed: U3.10 (IOB3), U4.5 (4a)
unnamed: U3.11 (IOB2), U4.6 (3a)
unnamed: U3.12 (IOB1), U4.7 (2a)
unnamed: U3.13 (IOB0), U4.8 (1a)
unnamed: U3.14 (IOA7), U9.1 (8a)
unnamed: U3.15 (IOA6), U9.2 (7a)
unnamed: U3.16 (IOA5), U9.3 (6a)
unnamed: U3.17 (IOA4), U9.4 (5a)
unnamed: U3.18 (IOA3), U9.5 (4a)
unnamed: U3.19 (IOA2), U9.6 (3a)
unnamed: U3.20 (IOA1), U9.7 (2a)
unnamed: U3.21 (IOA0), U9.8 (1a)
unnamed: U3.27 (BDIR), U7.10
unnamed: U3.29 (BC1), U7.13
unnamed: U6.3, U6.4, U6.12
unnamed: U5.14 (O1), U11.18 (~CE~)
unnamed: U5.15 (O0), U12.18 (~CE~)
unnamed: U5.12 (O3), U13.8 (~CS~), U14.8 (~CS~)
unnamed: U15.7 (O7), U23.11
unnamed: U3.24 (~A9~), U7.9, U7.11, U15.9 (O6)
unnamed: U15.10 (O5), U16.3, U16.5, U18.24 (~A9~)
unnamed: U15.11 (O4), U16.9, U16.11, U17.24 (~A9~)
unnamed: U16.1, U18.29 (BC1)
unnamed: U16.4, U18.27 (BDIR)
unnamed: U6.6, U7.8, U16.6, U16.8
unnamed: U16.10, U17.27 (BDIR)
unnamed: U6.11, U7.12, U16.2, U16.12
unnamed: U16.13, U17.29 (BC1)
unnamed: U8.14 (DOR), U17.17 (IOA4)
unnamed: U8.10 (Q3), U17.18 (IOA3)
unnamed: U8.11 (Q2), U17.19 (IOA2)
unnamed: U8.12 (Q1), U17.20 (IOA1)
unnamed: U8.13 (Q0), U17.21 (IOA0)
unnamed: U3.30 (D7), U17.30 (D7)
unnamed: U3.31 (D6), U17.31 (D6)
unnamed: U3.32 (D5), U17.32 (D5)
unnamed: U3.33 (D4), U17.33 (D4)
unnamed: U3.34 (D3), U17.34 (D3)
unnamed: U3.35 (D2), U17.35 (D2)
unnamed: U3.36 (D1), U17.36 (D1)
unnamed: U3.37 (D0), U17.37 (D0)
unnamed: U18.6 (IOB7), U19.1 (8a)
unnamed: U18.7 (IOB6), U19.2 (7a)
unnamed: U18.8 (IOB5), U19.3 (6a)
unnamed: U18.9 (IOB4), U19.4 (5a)
unnamed: U18.10 (IOB3), U19.5 (4a)
unnamed: U18.11 (IOB2), U19.6 (3a)
unnamed: U18.12 (IOB1), U19.7 (2a)
unnamed: U18.13 (IOB0), U19.8 (1a)
unnamed: U18.14 (IOA7), U22.1 (8a)
unnamed: U18.15 (IOA6), U22.2 (7a)
unnamed: U18.16 (IOA5), U22.3 (6a)
unnamed: U18.17 (IOA4), U22.4 (5a)
unnamed: U18.18 (IOA3), U22.5 (4a)
unnamed: U18.19 (IOA2), U22.6 (3a)
unnamed: U18.20 (IOA1), U22.7 (2a)
unnamed: U18.21 (IOA0), U22.8 (1a)
unnamed: U6.8, U23.1
unnamed: U23.3, U23.5, U24.5 (Q)
unnamed: U23.12, U24.3 (C)
unnamed: U24.2 (D), U24.6 (~Q)
WD: U6.10
~BUSACK~: J4.35, U10.23 (~BUSACK~)
~BUSREQ~: J4.26, R33.1, U10.25 (~BUSRQ~)
~CLK~: J4.29, U1.15 (CLK), U3.22 (CLOCK), U17.22 (CLOCK), U18.22 (CLOCK), U23.4
~HALT~: J4.37, U10.18 (~HALT~)
~INT~: J4.38, R1.1, U1.12 (INT), U10.16 (~INT~)
~IORQ~: J4.33, U1.10 (IORQ), U10.20 (~IORQ~)
~MREQ~: J4.30, U5.4 (E1), U10.19 (~MREQ~)
~NMI~: J4.25, R31.1, U10.17 (~NMI~)
~READ~: J4.31, U1.6 (RD), U6.1, U10.21 (~RD~), U11.20 (~OE~), U12.20 (~OE~)
~RESET~: J4.28, U1.17 (~RESET~), U3.23 (~RESET~), U10.26 (~RESET~), U17.23 (~RESET~), U18.23 (~RESET~), U23.2
~RFSH~: J4.36, U10.28 (~RFSH~)
~WAIT~: J4.27, R32.1, U10.24 (~WAIT~)
~WD~: R30.2, U21.7 (DIS)
~WRITE~: J4.34, U6.2, U10.22 (~WR~), U13.10 (~WE~), U14.10 (~WE~)

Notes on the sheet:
Volume Potentiometer Ground
Speaker Hi
Volume Potentiometer Center
+25V
Speaker Lo
-25V
Power Ground
Volume Potentiometer High
+5V
4.4 VAC Hi
4.4 VAC Lo
Bias
N/C
Input Shift-In
Input Data 3
Input Data 2
Input Data 1
Input Data 0

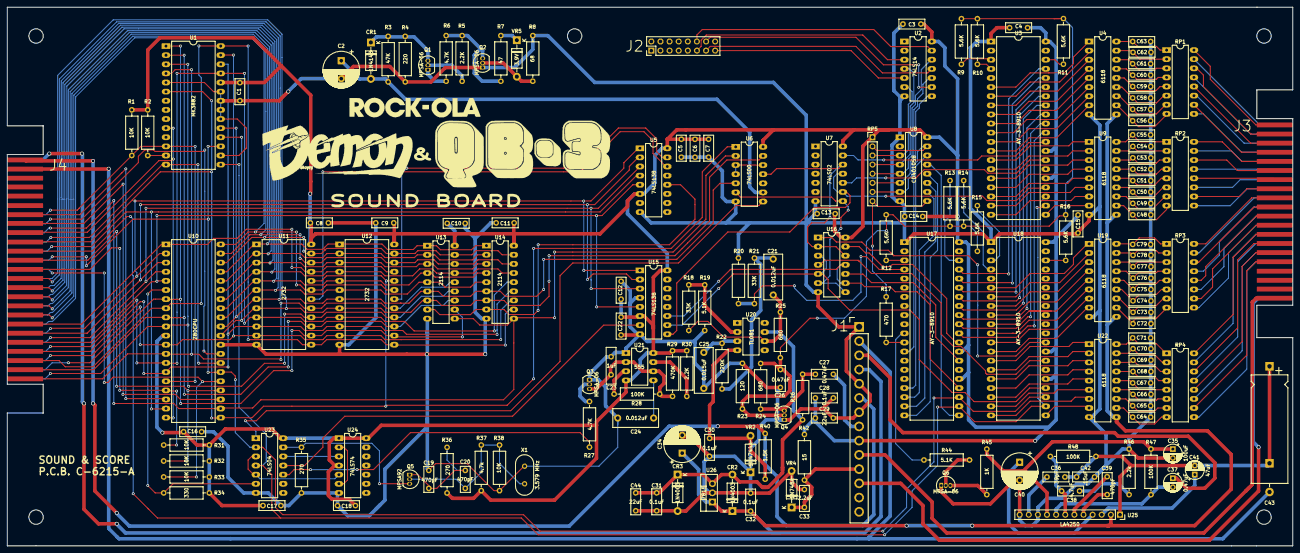
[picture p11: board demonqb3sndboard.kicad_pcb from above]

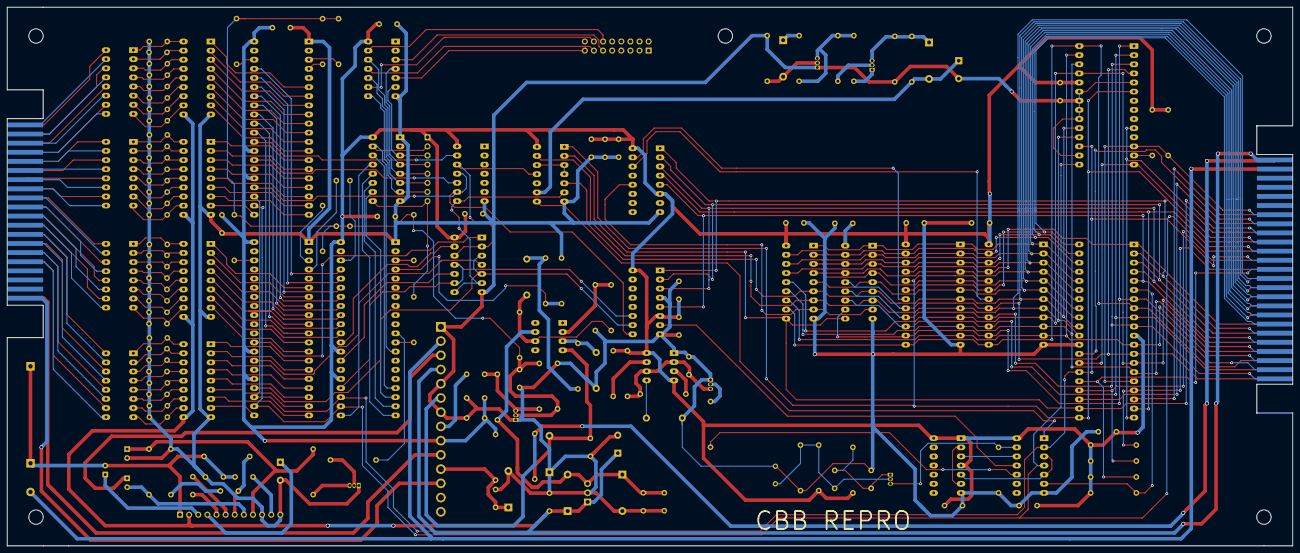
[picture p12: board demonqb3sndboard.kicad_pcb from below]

Board: 2 copper layers, 358.0 x 150.0 mm, 169 parts (2 on the bottom side), 238 nets.
